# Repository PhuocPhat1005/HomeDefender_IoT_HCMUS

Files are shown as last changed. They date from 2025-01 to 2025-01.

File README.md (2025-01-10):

# **HomeDefender IoT (an alarm system integrated with a camera)**

## **1. Introduction**
* In today's technological era, the Internet of Things (IoT) has been growing rapidly, being applied in various aspects of life and bringing numerous benefits and conveniences to people's lives. The development of devices to protect homes remotely via the Internet is no exception. 

* The HomeDefender product is an anti-theft device designed to protect homes by combining sensors, logical rules, and Internet connectivity. This allows homeowners to easily monitor and safeguard their homes anytime and anywhere. With its compact design, stability, and a simple, user-friendly website interface, the product promises to deliver an excellent and reassuring experience for users.

## **2. System Functionality Description**

* The device utilizes a **PIR** motion sensor to detect if someone approaches the house (the monitored area). Depending on the level of intrusion, the device will activate different modes:
	* **Safe Mode (Mode 1 – Safe System Mode):** The LED light remains blue if no intruders are detected.
	* **Alert Mode (Mode 2 – Alert System Mode):** The device will flash a red LED, and the buzzer will emit a "beep-beep-pause" sound pattern for 10 seconds. After 10 seconds, the system will return to Mode 1. If the intruder remains in the alert zone after this period, a notification will be sent to the user's email. This mode will repeat continuously until no further intrusion is detected.
	* **Emergency Alert Mode (Mode 3 – Emergency Warning System Mode):** In emergency situations, the user can activate the emergency alert mode via the website through the **Device Controls** page by pressing the “FORCE ALERT RIGHT NOW” button. The system will immediately emit a continuous buzzer sound and keep the red LED light on until this mode is deactivated. Simultaneously, the system will send a notification to the user's email.
* In addition, the device is equipped with a camera that can stream video anytime the user desires, allowing them to easily monitor and protect their home. The camera also has the capability to take photos automatically or manually, capturing images of intruders as evidence for reporting criminal activity.
* To ensure the captured photos are well-lit, the device includes a flash that can automatically turn on/off based on signals from a light sensor (the darker the environment, the brighter the flash). Alternatively, the user can manually control the flash through the website as a method of intrusion warning.
* The system stores the photos and records the number of alerts issued each day, along with specific timestamps. This feature helps users track and analyze the security situation in their area more effectively.
* If the system determines that the intruder poses a significant threat, an email will be sent to the user immediately to alert them of the potential danger to their home.
* Additionally, the device is connected to a website for easy use and management by the user. After logging in, the user can perform various functions such as:
	-   Adjusting the operating time.
	-   Turning the device on/off.
	-   Manually capturing photos.
	-   Streaming video.
	-   Viewing the alert history.
	-   Accessing stored photos.
* All of these actions can be done quickly and easily through the user-friendly web interface.

## **3. Members Distribution**
| Student ID | Full Name | Tasks |
|:---:| --- | --- |
|  22127322  | Lê Phước Phát | Embedded Developer |
|  22127388  | Tô Quốc Thanh | UI/UX Developer |
|  22127441  | Thái Huyễn Tùng | Reporter |

## **4. Video Demo**
<!-- BEGIN YOUTUBE-CARDS -->
HomeDefender IoT Demo (https://www.youtube.com/watch?v=ZLpqiuz0C70)
<!-- END YOUTUBE-CARDS -->

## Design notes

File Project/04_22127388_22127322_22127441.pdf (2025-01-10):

Project: HomeDefender | Nhóm 4

ĐẠI HỌC QUỐC GIA THÀNH PHỐ HỒ CHÍ MINH

ĐẠI HỌC KHOA HỌC TỰ NHIÊN HỒ CHÍ MINH

KHOA CÔNG NGHỆ THÔNG TIN

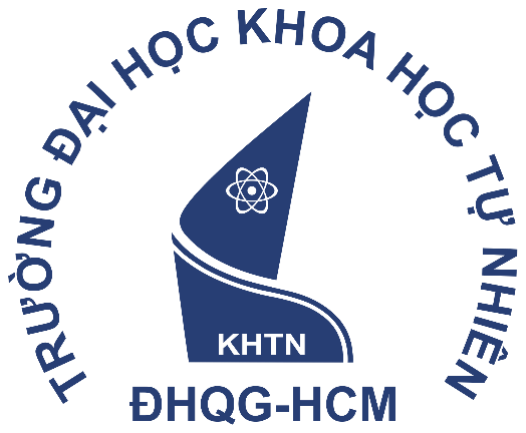
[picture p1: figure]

BÁO CÁO ĐỒ ÁN CUỐI KỲ

VẬT LÝ CHO CÔNG NGHỆ THÔNG TIN

Project: HomeDefender

Giáo viên hướng dẫn:

Thầy: Lê Quốc Hòa

Thầy: Cao Xuân Nam

Thầy: Đặng Hoài Thương

Danh sách thành viên của nhóm 4:

Tô Quốc Thanh – 22127388 (Nhóm trưởng)

Lê Phước Phát – 22127322

Thái Huyễn Tùng – 22127441

## Mục lục

## Phần 1: Giới thiệu

1.1 Giới thiệu
Trong thời đại công nghệ hiện nay, Internet of Things đã và đang phát triển vô cùng mạnh mẽ, được áp dụng vào nhiều lĩnh vực trong đời sống, mang lại nhiều lợi ích và tiện nghi cho cuộc sống của con người. Và việc phát triển thiết bị để bảo vệ ngôi nhà từ xa thông qua Internet cũng không nằm ngoại lệ.

Sản phẩm HomeDefender là thiết bị chống trộm, bảo vệ ngôi nhà bằng cách kết hợp các thiết bị cảm biến, các quy tắc logic cùng với kết nối Internet, từ đó giúp chủ nhà có thể dễ dàng theo dõi và bảo vệ ngôi nhà của mình ở bất kì đâu và bất kì lúc nào. Với thiết kế nhỏ gọn, ổn định cùng giao diện website đơn giản, thân thiện, sản phẩm hứa hẹn sẽ mang lại trải nghiệm tuyệt vời và an tâm cho người sử dụng.
1.2 Mô tả chức năng của toàn hệ thống

Thiết bị sử dụng Cảm biến chuyển động PIR để kiểm tra nếu có người đến gần nhà (khu vực quan sát), tùy theo mức độ xâm nhập mà thiết bị sẽ có những chế độ khác nhau:

+ Chế độ an toàn (mode 1 – safe system mode): Luôn bật đèn Led màu xanh nếu không phát hiện kẻ xâm nhập.

+ Chế độ báo động dựa vào cảm biến hồng ngoại (mode 2 – alert system mode): Thiết bị sẽ nhấp nháy Led đỏ và buzzer sẽ phát tiếng kêu beep beep pause trong vòng 10 giây, sau 10 giây hệ thống sẽ trở lại mode 1, nếu tên trộm vẫn còn trong vùng báo động sau 10 giây thì sẽ gửi thông báo đến mail. Chế độ này sẽ được lặp lại liên tục cho đến khi không còn phát hiện xâm nhập.

+ Chế độ báo động khẩn cấp (mode 3 – emergency warnings system mode): Nếu trong tình huống khẩn cấp, người dùng có thể kích hoạt chế độ báo động khẩn cấp trên Website thông qua trang Device Controls bằng cách bấm nút “FORCE ALERT RIGHT NOW”. Ngay lập tức hệ thống sẽ phát ra tín hiệu buzzer kêu liên hồi và Led đỏ sáng liên tục cho đến khi chế độ này được tắt. Đồng thời, chế độ này cũng sẽ thông báo cho người dùng qua mail.

Bên cạnh đó, thiết bị còn được trang bị Camera để có thể Stream Video bất kì lúc nào mà người dùng muốn để có thể dễ dàng kiểm tra và bảo vệ ngôi nhà của mình. Ngoài ra, Camera này còn có tác dụng chụp ảnh để lưu lại những bức ảnh của kẻ xâm nhập một cách tự động hoặc thủ công, dùng để làm bằng chứng tố cáo tội phạm.

Để đảm bảo các bức ảnh có đầy đủ ánh sáng, thiết bị có trang bị đèn Flash có thể tự động bật/ tắt khi chụp ảnh dựa vào tín hiệu của cảm biến ánh sáng (trời càng tối thì đèn càng sáng), hoặc người dùng có thể bật/ tắt đèn Flash này thủ công thông qua Website như một phương thức cảnh báo xâm nhập.

Hệ thống sẽ lưu lại những bức ảnh và số lần cảnh cáo mỗi ngày với thời gian cụ thể, từ đó giúp người dùng dễ dàng thống kê, theo dõi tình hình an ninh trong khu vực.

Trong trường hợp kẻ xâm nhập được hệ thống đánh giá là nguy hiểm, sẽ có một email được gửi đến người dùng để nhanh chóng cảnh báo cho họ về nguy cơ ngôi nhà bị xâm nhập.

Ngoài ra, thiết bị còn được kết nối với Website để người dùng dễ dàng sử dụng và quản lí, sau khi đăng nhập, người dùng có thể thực hiện các chức năng như : điều chỉnh thời gian hoạt động, bật/ tắt thiết bị, chụp ảnh thủ công, stream video, xem lịch sử cảnh báo, xem ảnh đã lưu,.... một cách dễ dàng và nhanh chóng.

## Phần 2: Chi tiết sản phẩm

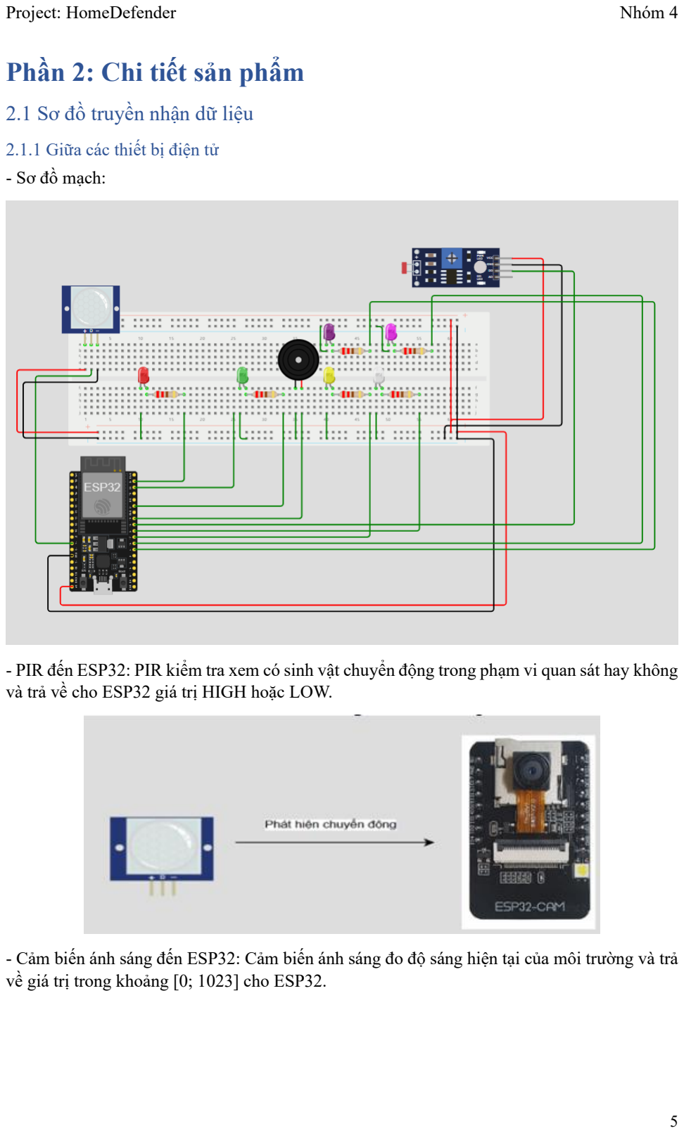
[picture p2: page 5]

2.1 Sơ đồ truyền nhận dữ liệu

2.1.1 Giữa các thiết bị điện tử
- Sơ đồ mạch:
- PIR đến ESP32: PIR kiểm tra xem có sinh vật chuyển động trong phạm vi quan sát hay không và trả về cho ESP32 giá trị HIGH hoặc LOW.
- Cảm biến ánh sáng đến ESP32: Cảm biến ánh sáng đo độ sáng hiện tại của môi trường và trả về giá trị trong khoảng [0; 1023] cho ESP32.

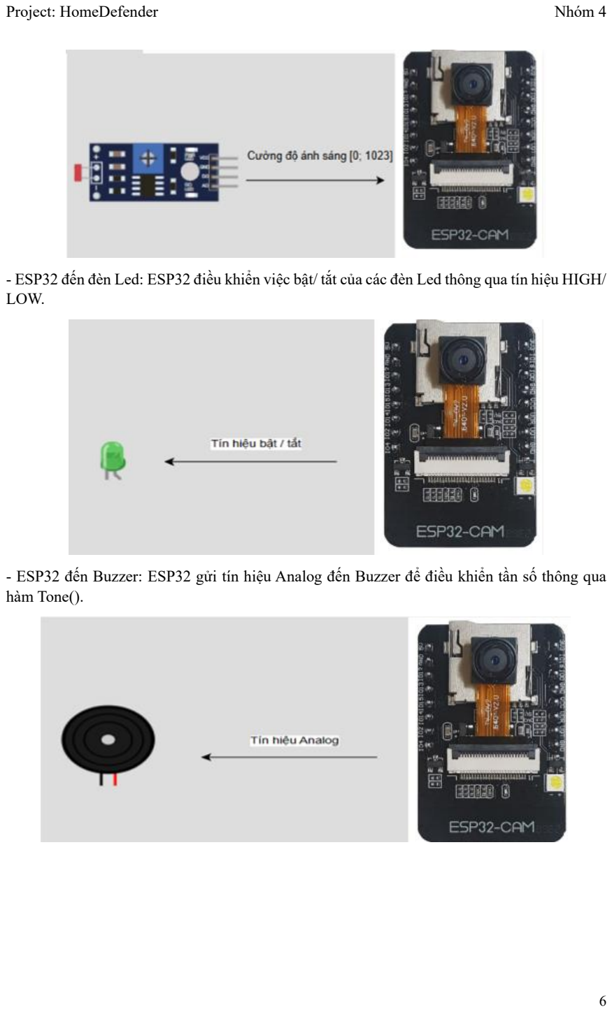
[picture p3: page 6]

- ESP32 đến đèn Led: ESP32 điều khiển việc bật/ tắt của các đèn Led thông qua tín hiệu HIGH/ LOW.
- ESP32 đến Buzzer: ESP32 gửi tín hiệu Analog đến Buzzer để điều khiển tần số thông qua hàm Tone().

2.1.2 Giữa các thiết bị điện tử với website

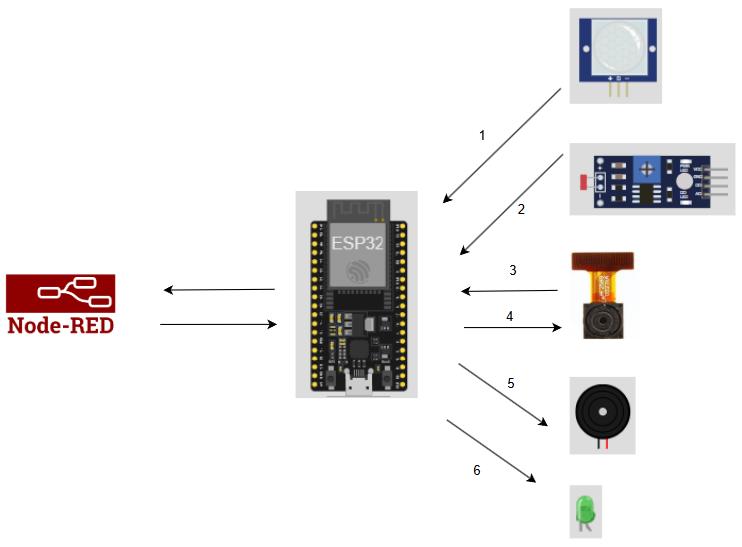
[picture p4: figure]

Website gửi/ nhận thông tin với các thiết bị điện tử thông qua trung tâm điều khiển là ESP32.

- (1): PIR gửi tín hiệu có/ không phát hiện xâm nhập đến cho Website thông qua giá trị HIGH/ LOW.
- (2): Cảm biến ánh sáng gửi giá trị ánh sáng đo được hiện tại đến Website thông quá giá trị trong khoảng [0; 1023], từ đó Website sẽ biết được trạng thái ánh sáng hiện tại là isDay/ isNight.
- (3): Camera Streaming và gửi hình ảnh/ video quay được trực tiếp đến Website thông qua URL (URL này sẽ là http server được cấu hình sẵn theo cấu trúc sau: http://<WIFI LOCAL IP>/mjpeg/1” với WIFI LOCAL IP sẽ là địa chị local của WIFI mà thiết bị đang được cấu hình).
- (4): Dựa vào đường dẫn stream link đã được cấu hình ở luồng (3), chúng ta sẽ thực hiện tách frame từng ảnh và lưu vào database.
- (5): Website điều khiển Buzzer phát ra âm thanh cảnh báo thông qua giá trị analog.
- (6): Website điều khiển đèn Led bật/ tắt thông qua giá trị HIGH/ LOW.

2.1.3 Giữa website với Firesbase
A. Phần Authentication:

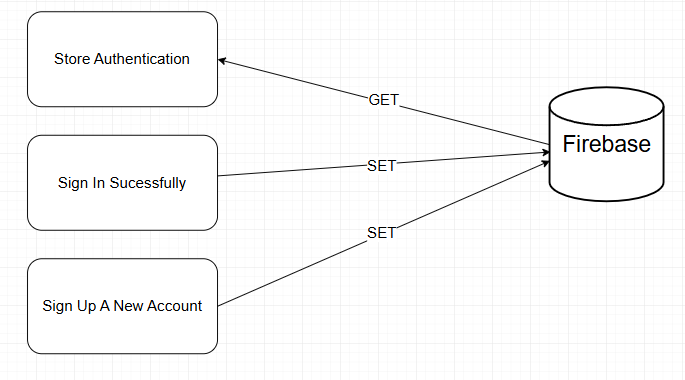
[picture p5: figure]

Luồng 1: Từ Firebase đến Store Authentication

Dữ liệu từ Firebase được gọi và truyền đến function Store Authentication, hàm này sẽ nhận được thông tin người dùng ở trạng thái chưa xác thực và tiến hành lưu nó vào toàn cục.

Luồng 2: Từ Sign In Successfully đến Firebase

Sau khi người dùng đăng nhập thành công thì lúc này thông tin xác thực sẽ trở thành true, sau đó nó được gửi và lưu trữ lên trên Firebase.

Luồng 3: Từ Sign Up A New Account đến Firebase

Lúc này người dùng sẽ điền thông tin đăng ký vào form, sau đó thông tin này được gửi và lưu trữ trên Firebase trong trạng thái chưa xác thực.

* Lưu ý: Trạng thái xác thực ở đây nghĩa là khi người dùng đăng nhập thành công sẽ được chuyển đến các trang chức năng đồng thời trạng thái xác thực sẽ trở thành true. Tuy nhiên, nếu người dùng tiến hành đăng xuất thì trạng thái xác thực sẽ trở thành false.

B. Phần Device Controls:

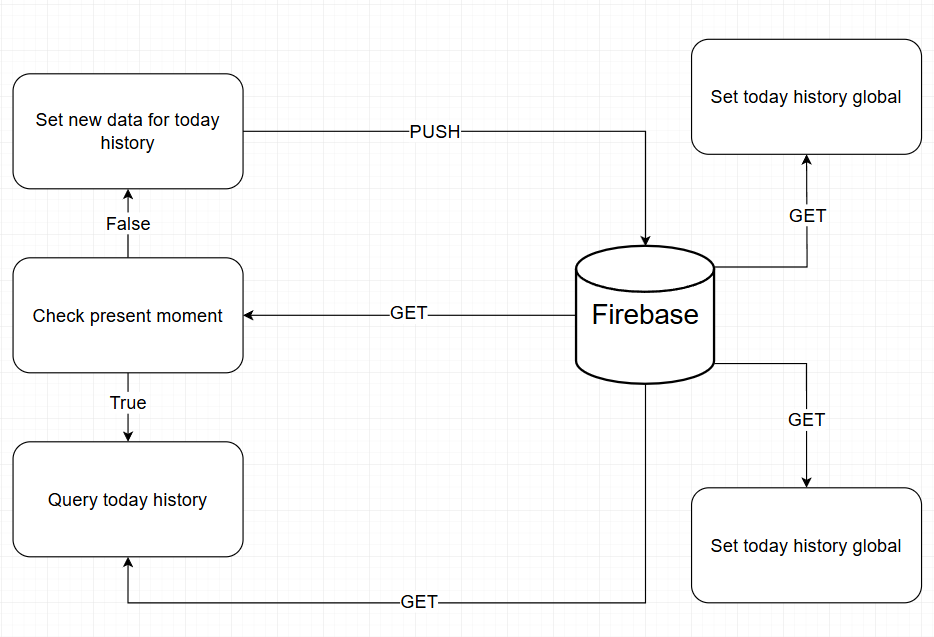
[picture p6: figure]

Luồng 1: Từ Firebase đến Check present moment

Dữ liệu từ Firebase (cụ thể là trường History) sẽ được gửi đến hàm Check present moment để kiểm tra xem dữ liệu về lịch sử cho ngày hôm nay đã tồn tại hay chưa. Đồng thời tạo ra biến toàn cục history_object_key để lưu trữ key object tương ứng với object của lịch sử hôm nay.

Luồng 2: Từ Firebase dến Query today history

Sau khi kiểm tra rằng lịch sử ngày hôm nay đã được tạo thì hàm sẽ tiến hành lấy dữ liệu từ Firebase ứng với biến toàn cục history_object_key. Sau đó dữ liệu đó được đưa vào hàm Set today history global để lưu vào hiến toàn cục today_history.

Luồng 3: Từ Set new data for today history đến Firebase

Nếu lịch sử cho ngày hôm này chưa tồn tại thì sẽ tiến hành lưu lịch sử cho ngày hôm nay vào 1 object và gửi nó đến Firebase để lưu trữ. Sau đó dữ liệu đó được đưa vào hàm Set today history global để lưu vào hiến toàn cục today_history.

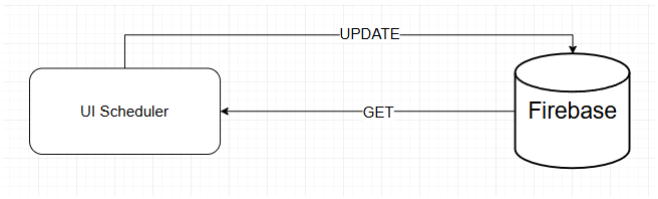
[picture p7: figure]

Luồng 4: Từ Firebase đến UI Shceduler (Giao diện xếp lịch hoạt động cho thiết bị)

Ở phần này, trang web sẽ tiến hành lưu lại trên Firebase lịch hoạt động của thiết bị mà người dùng đã chuẩn bị. Nếu người dùng có cập nhật hay thêm, xóa và sửa lịch thì thông tin đó sẽ được cập nhật lại trong Firebase. Firebase sẽ trả về thông tin lịch sau khi đã chỉnh sửa để hiện ra giao diện trang web.

C. Phần Advanced Settings:

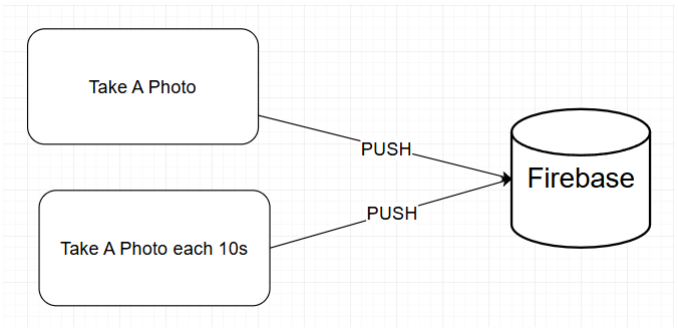
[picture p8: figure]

Luồng 1: Chụp ảnh thủ công đến Firebase

Trong lúc người dùng streaming video, khi nhấn nút chụp ảnh, lúc này ảnh chụp sẽ được gửi đến Firebase để lưu trữ kèm theo 1 số thông tin cụ thể về thời gian ảnh chụp.

Luồng 2: Chụp ảnh tự động mỗi 10s nếu trong vùng nguy hiểm đến Firebase

Khi vật thể bị cảnh bảo và trong khoảng 10 giây kể từ lúc bắt đầu cảnh báo, ảnh sẽ được chụp tự động mỗi 10 giây và được lưu trữ trên Firebase.

D. Phần History:

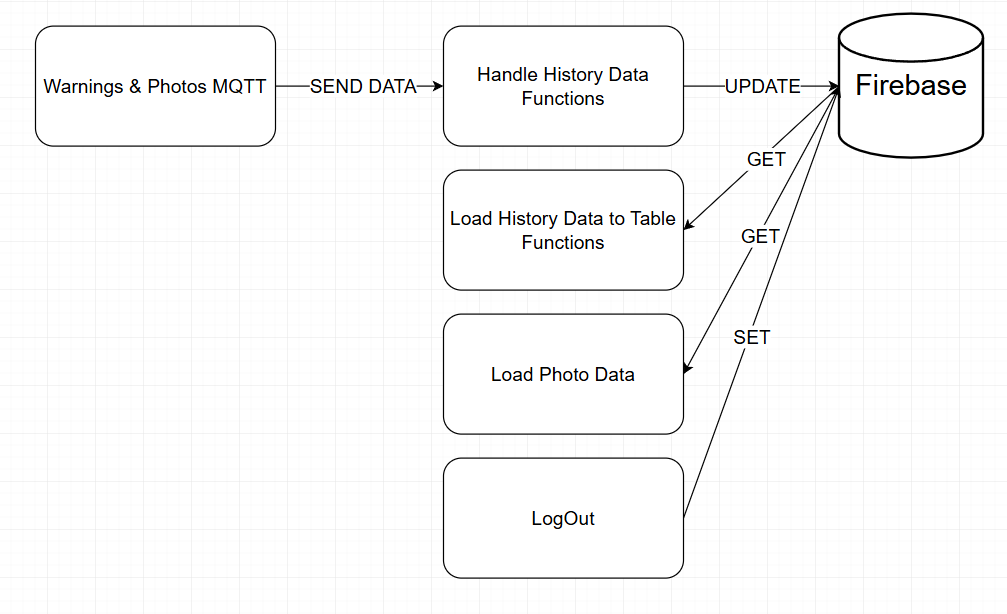
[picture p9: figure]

Luồng 1: MQTT đến Handle History data Functions đến Firebase

Nhận thông tin về số lần warning và số lượng ảnh thông qua MQTT. Sau đó, những dữ liệu này được xử lý thông qua 1 số hàm để trả về dữ liệu lịch sử thích hợp. Cuối cùng, những dữ liệu đã qua xử lý này sẽ được cập nhật và lưu trữ lên trên Firebase.

Luồng 2: Firebase đến Load History Data to Table Functions

Sau khi có được dữ liệu lịch sử, Firebase tiến hành gửi những dữ liệu đó về cho website (Dữ liệu lúc này chỉ là số lượng cảnh báo và số hình ảnh trong ngày). Lúc này, website sẽ sử dụng những dữ liệu đó và tiến hành hiển thị lên trên website.

Luồng 3: Firebase đến Load Photo Data

Lúc này, trang website sẽ nhận dữ liệu hình ảnh từ Firebase và tiến hành hiển thị ra chúng. Người dùng sẽ chọn 1 tấm ảnh tại 1 thời điểm xác định trong menu để tiến hành xem hình ảnh.

Luồng 4: Logout đến Firebase

Khi người dùng bấm đăng xuất, website sẽ gửi về Firebase thông tin người dùng và thay đổi trạng thái xác thực (đang đăng nhập) thành false và người dùng được chuyển về màn hình đăng nhập.

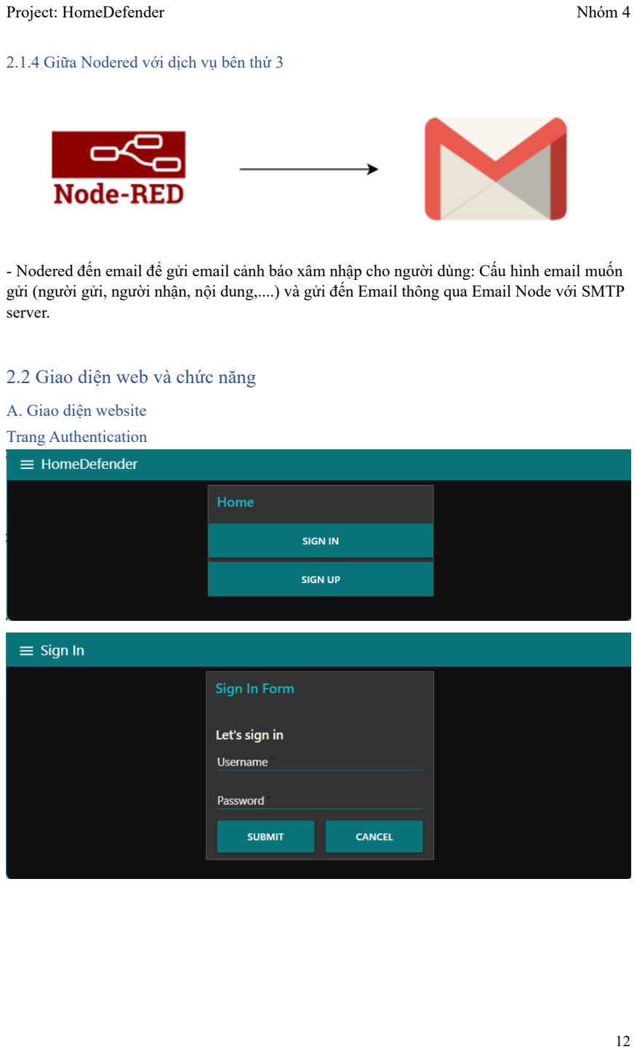
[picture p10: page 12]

2.1.4 Giữa Nodered với dịch vụ bên thứ 3

- Nodered đến email để gửi email cảnh báo xâm nhập cho người dùng: Cấu hình email muốn gửi (người gửi, người nhận, nội dung,....) và gửi đến Email thông qua Email Node với SMTP server.

2.2 Giao diện web và chức năng

A. Giao diện website
Trang Authentication

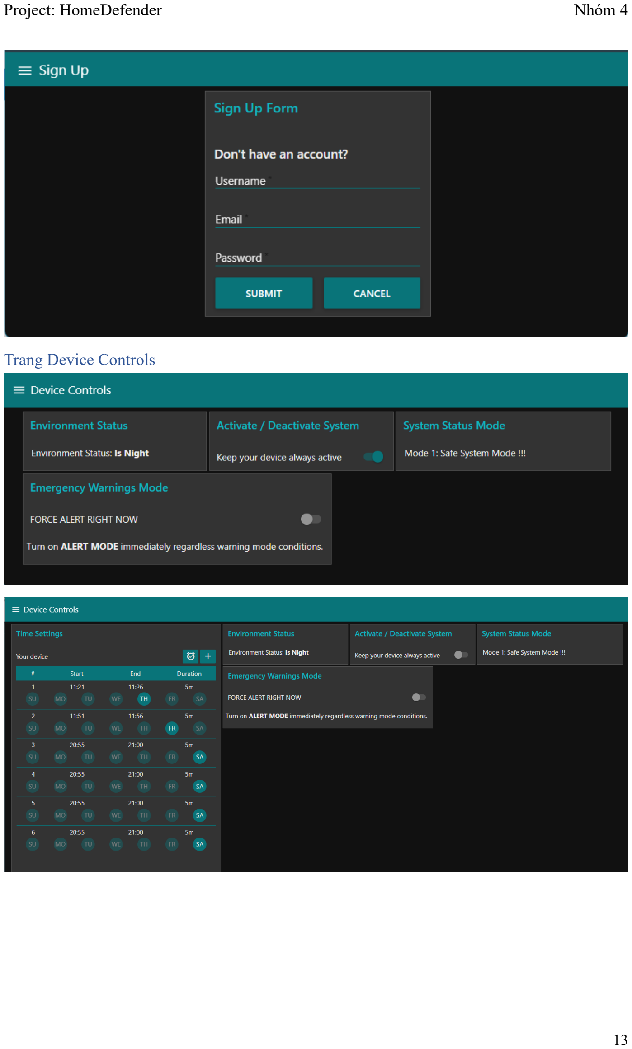
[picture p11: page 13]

Trang Device Controls

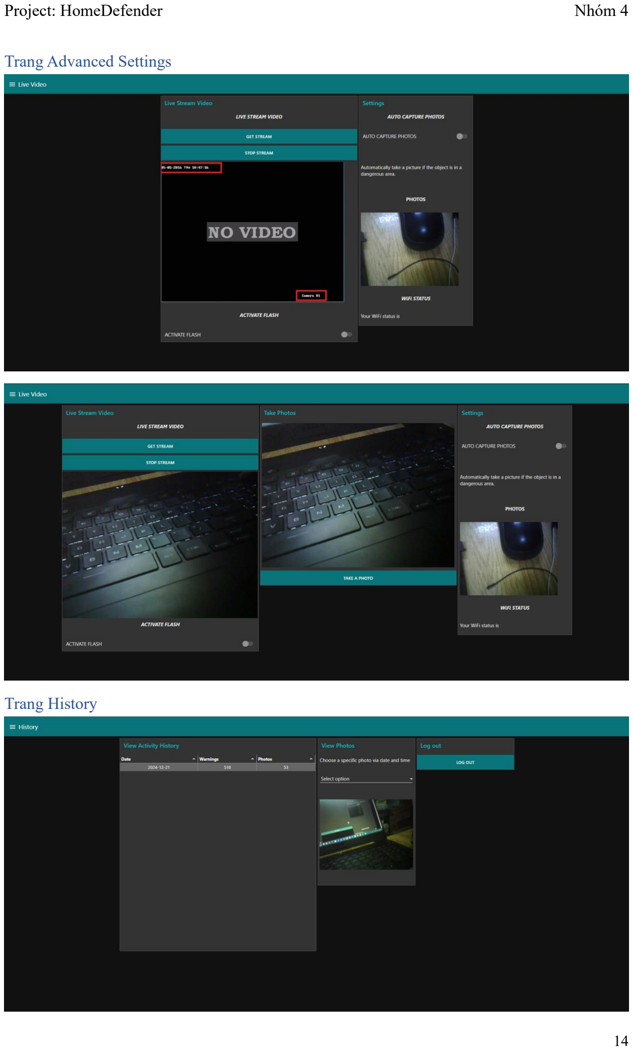
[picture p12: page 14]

Trang Advanced Settings

Trang History

B. Chức năng website
Trang Authentication
Ở trang chủ, trang web sẽ có 2 nút bấm chuyển đến trang đăng nhập và đăng ký.

Ở trang đăng ký, người dùng sẽ:

- Nhập tên tài khoản - Username
- Nhập Email – Email này sẽ dùng để nhận các cảnh báo
- Nhập mật khẩu – Password

Ở trang đăng nhập, người dùng chỉ cần đăng nhập theo Username và Password vừa tạo ở trang đăng ký.

Trang Device Controls
Trong Warning Voice, người dùng mặc định sẽ có âm thanh cảnh báo là beep pause beep.

Trong Photoresistor Sensor, người dùng có thể xem được trạng thái ánh sáng của môi trường xung quanh, quang trở còn có khả năng điều chỉnh độ sáng đèn flash cho phù hợp với môi trường.

Trong Actrive Device, người dùng sẽ được bật mặc định, tức là thiệt bị sẽ luôn hoạt động. Tuy nhiên, người dùng vẫn có thể chỉnh giờ hoạt động của thiết bị theo lịch trình của mình. Để thực hiện chức năng này, người dùng cần phải tắt bỏ đi chức năng hoạt động 24/24 của thiết bị. Sau đó tiến hành chọn và cài đặt lịch trình phù hợp.

Trong System Mode, người dùng sẽ xem được Mode hiện tại của hệ thống. Thông tin sẽ được hệ thống cập nhật bằng một message mỗi khi nó thay đổi Mode.

Trang Advanced Settings
Mặc định, chế độ streaming video sẽ tắt, khi người dùng bấm vào nút Get Stream thì trả về tín hiệu true cho nút Switch, trang web sẽ truy cập vào đường dẫn được trả từ server mqtt “http://<esp32-ip>/mjpeg/1”, trong đó esp32-ip là địa chỉ local ip của wifi mà server đang dùng. Sau đó Web sẽ hiển thị video streaming cho người dùng. Ngược lại khi bấm nút Stop Stream thì trả về tín hiệu false cho nút Switch và lấy hình ảnh “No video” mặc định hiển thị cho người dùng.

Đồng thời, người dùng có thể chụp bất cứ tấm ảnh nào mà mình muốn trong quá trình streaming, bức ảnh được chụp tại thời điểm đó sẽ được hiển thị ngay lập tức trong phần Take Photos.

Bên cạnh đó, người dùng có thể dùng chức năng Chụp hình tự động ở khu vực mà Camera đang quan sát bằng cách bấm vào nút Auto Capture.

Chức năng Alert Mode (Alert Immediately) giúp cho người dùng có thể bật được cảnh báo ở bất kỳ thời điểm nào, kể cả vật thể chưa tiếp cận khu vực cảnh báo. Chức năng này có thể giúp người dùng xua đuổi một số vật thể trước khi chúng cố gắng tiếp cận ngôi nhà. Chức năng này mặc định sẽ được tắt. Hệ thống sẽ hiển thị đèn đỏ sáng liên tục và loa buzzer kêu liên hồi.

Active Flash là chức năng giúp cho người dùng bật được đèn Flash để chiếu sáng. Khi bật đèn Flash sẽ chiếu sáng ở mức tối đa. Chức năng này mặc định cũng sẽ được tắt.

Dòng cuối sẽ là dòng thông báo trạng thái WiFi đã kết nối hay chưa. Nếu kết nối WiFi thành công thì sẽ là TURNED ON còn thất bại sẽ là TURNED OFF.

Trang History
Chức năng View Activity History giúp người dùng xem được lịch sử hoạt động của thiết bị theo ngày. Bảng gồm có 3 cột, mỗi cột người dùng để có thể sắp xếp theo thứ tự tăng hoặc giảm dần:
- Cột Date nghĩa là ngày, cột này sẽ hiển thị thời gian theo chuẩn: YYYY-MM-DD (Năm – Tháng – Ngày).
- Cột Warnings nghĩa là số lần cảnh báo ghi nhận được trong ngày.
- Cột Photos nghĩa là số hình ảnh chụp được trong ngày.

Chức năng View Photos giúp người dùng có thể xem ảnh đã chụp được theo thời điểm chụp tấm ảnh đó. Người dùng chỉ cần chọn khung thời điểm mình muốn xem trong ô selection thì tấm ảnh tương ứng sẽ được hiển thị ra.

Chức năng Logout (Đăng xuất) giúp người dùng đăng xuất ra khỏi trang web.

C. Cấu hình Website

Trang Authentication
Function Verify SignIn

Bước 1: Lấy thông tin từ Form đăng nhập

Bước 2: Lấy thông tin lưu trữ trong biến toàn cục (thông tin này đã được đọc từ Firebase và lưu vào toàn cục)

Bước 3: Nếu 2 thông tin trên là tồn tại thì tiến hành so sánh cái trường dữ liệu, nếu thỏa thì trường is_auth (xác thực) sẽ là true, nếu không thì trường is_auth có giá trị là false.

Function Verify SignUp
Hàm này nhận dữ liệu vào từ Form đăng ký, sau đó tiến hành gán trường xác thực (is_auth) mặc định là false.

Luồng cơ bản:

Lúc đầu sẽ chỉ hiện thị những trang đăng nhập, đăng ký và trang chủ.

Khi người dùng đăng nhập thành công thì sẽ di chuyển người dùng để những trang điều khiển và ẩn trang đăng nhập, đăng ký và trang chủ đi.

Trang Device Controls
Function Preprocessing Scheduler

Hàm này nhận dữ liệu trả về từ Firebase, chuyển đổi thành dạng JSON. Đồng thời trả về trường msg.topic = “update” để Node UI Scheduler có thể cập nhật lịch.

Function Handle Empty Scheduler

Nếu dữ liệu từ Firebase trả về là rỗng hay null thì hàm này sẽ trả về false thông qua MQTT để thông báo rằng lịch rỗng.

Function Day/Night

Hàm này chịu trách nhiệm hiển thị thông tin Sáng/Tối. Kiểm tra msg.payload và chia trường hợp nếu là false nghĩa là sáng còn true nghĩa là tối.

Luồng cơ bản

Dữ liệu nhận tự động từ Firebase, đó là dữ liệu lưu khung thời điểm hoạt động của thiết bị.

Nếu dữ liệu tồn tại, nó sẽ được tiền xử lý và nạp nào Node UI Scheduler (Node Lịch). Node này trả về 2 tham số:

- Tham số thứ nhất là một object JSON lưu thời gian đã được thiết lập.
- Tham số thứ hai nghĩa là nếu thời gian thực tế trùng với thời gian trong lịch sẽ trả về true, ngược lại là false. Các giá trị này sẽ được gửi qua MQTT để kiểm tra thiết bị hoạt động hay không hoạt động.

Nếu dữ liệu không tồn tại, nó sẽ được gửi về MQTT với giá trị false nhằm thông báo lịch rỗng. Và thiết bị sẽ không hoạt động.

Mặc định sẽ ở chế độ hoạt dộng 24/24, nếu người dùng tắt chế độ này, thiết bị sẽ tự động chuyển qua giao diện lịch hoạt động như mô tả bên trên. Và ngược lại.

Người dùng có thể xem được ngoài trời là sáng hay tối thông qua message từ MQTT Photoresistor.

Mặc định thiết bị phát tiếng pause beep pause để cảnh báo. Âm thanh này không thể thay đổi.

Trang Advanced Settings
Function Store current image

Nhận hình ảnh từ MQTT, tiến hành lưu bức ảnh đó kèm với mốc thời gian của bức ảnh đó vào biến global. Thiết lập thêm trường src trong msg.src dùng để hiển thị ảnh/video thông qua Node template.

Function Take a photo

Lấy ra bức ảnh hiện tại từ biến toàn cục global được lưu từ hàm Store current image, sau đó gửi về Firebase để lưu bức ảnh được chụp. Đồng thời gửi giá trị true về MQTT để thông báo làm bật đèn Led ứng với lúc chụp ảnh.

Function Store Capture Photo each 10s

Hàm này nhận hình ảnh thông qua MQTT, tiến hành lưu hình ảnh với mốc thời gian của bức ảnh đó vào Firebase.

Luồng cơ bản

Mặc định streaming video được tắt, khi bật sẽ hiển thị đồng thời cửa sổ chụp ảnh kế bên để người dùng chụp ảnh và xem ảnh mới chụp ngay lập tức.

Chức năng chụp ảnh mỗi 10 giây sẽ tự động chụp ảnh nếu như có vật thể trong vùng cảnh báo quá 10 giây.

Chức năng Alert Mode dùng để bật cảnh báo bất kể vật thể có hay không có trong vùng cảnh báo.

Chức năng Active Flash dùng để bật Flash. Có thể dùng để soi sáng hay chụp ảnh và streaming video.

Chức năng xem trạng thái kết nối WiFi.

Trang History
Function Handle History Data

Đầu tiên tạo ngày giờ hôm nay đảm bảo định dạng: YYYY-MM-DD.

Tiếp theo, lấy ra lịch sử ngày hôm nay thông qua biến global today_history.

Kiểm tra payload của warnings và photos để xác định xem số lượng cảnh báo hay hình ảnh có thêm hay vẫn giữ nguyên.

Tạo ra một object lưu thông tin dữ liệu. Cập nhật lại biến toàn cục today_history là object đó.

Tạo ra dường dẫn động thông qua biến toàn cục history_object_key để đảm báo rằng dữ liệu mới được lưu đúng object chứa dữ liệu của lịch sử cho ngày hôm nay.

Function Preprocessing data image

Do dữ liệu trả về một object chứa các object mà các object được chứa lại chứa những thông tin của 1 ảnh nên logic sẽ có 2 vòng lặp.

Vòng lặp thứ nhất sẽ lặp qua các key trong object lớn ứng với mỗi key ta sẽ lấy ra được 1 object chứa các trường thông tin 1 ảnh.

Vòng lặp thứ 2 sẽ lặp qua những key của object nhỏ, ứng với mỗi key của object nhỏ ta sẽ lấy được các giá trị của nó sau đó lưu vào biến tạm và đẩy nó vào mảng kết quả khi kết thúc vòng lặp thứ 2.

Biến msg.options sẽ là 1 mảng những object với một object sẽ có key là cột mốc thời gian của bức ảnh và value là bức ảnh.

Luồng cơ bản

Trang web sẽ nhận MQTT về số lần cảnh báo và số ảnh chụp được liên tục.

Trang web sẽ nhận dữ liệu lịch sử mới nhất từ Firebase liên tục, đồng nghĩa rằng những thông số lịch sử sẽ được cập nhật liên tục và người dùng có thể thấy được mà không cần tải lại trang.

Trang web cũng sẽ nhận những thông tin hình ảnh mới nhất để đưa vào trang hiển thị cho người dùng. Họ có thể xem ảnh thông qua menu để chọn.

Nút đăng xuất giúp người dùng đăng xuất khỏi trang web.

2.3 Sản phẩm thực tế và thiết kế 3D

- Hình ảnh sản phẩm thực tế:

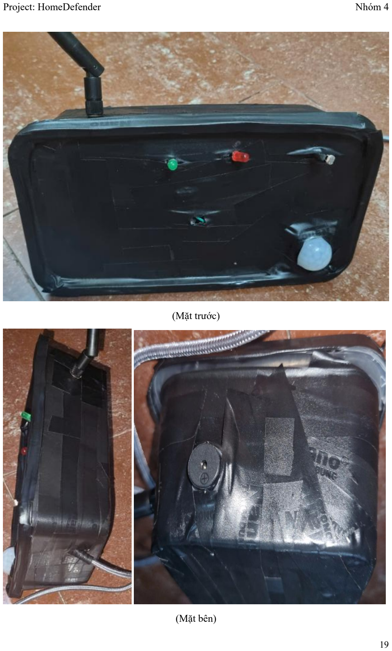
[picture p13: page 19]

(Mặt trước)

(Mặt bên)

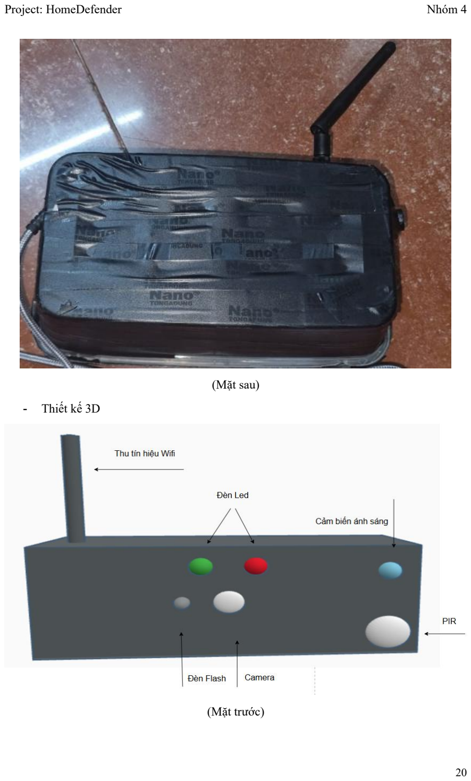
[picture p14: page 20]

(Mặt sau)

- Thiết kế 3D

(Mặt trước)

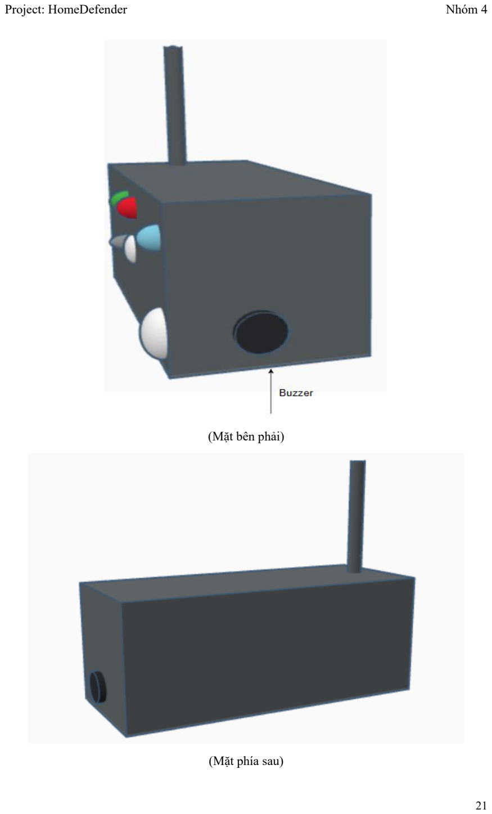
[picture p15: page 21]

(Mặt bên phải)

(Mặt phía sau)

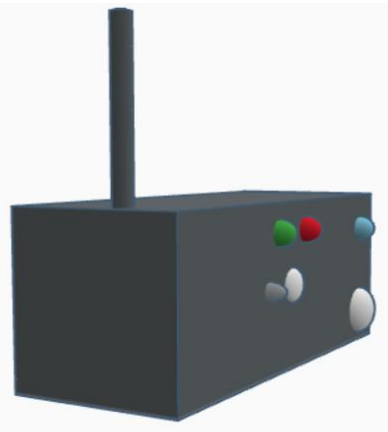
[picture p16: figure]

(Mặt bên trái)

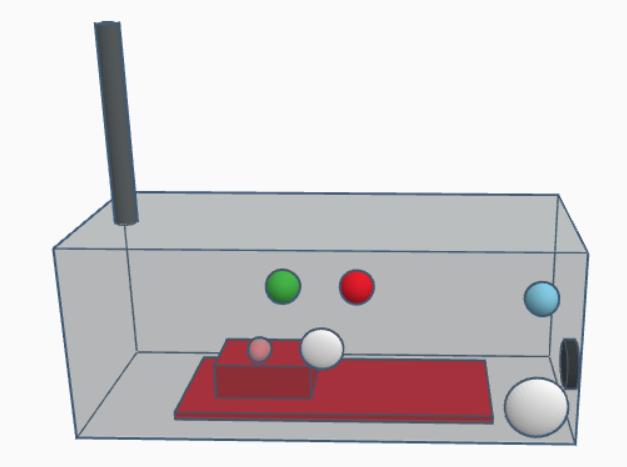
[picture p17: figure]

(Mặt trước và bản mạch)

## Phần 3: Chi tiết linh kiện

3.1. Sản phẩm thực tế
STT | Tên linh kiện | Số lượng
1 | ESP32-CAM[1] | 1
2 | Cảm Biến Chuyển Động Pir HC – Sr501[2] | 1
3 | Cảm biến ánh sáng | 1
4 | LED xanh | 1
5 | LED đỏ | 1
6 | Buzzer | 1
7 | Điện trở 220 ohm | 4
8 | Testboard | 1

[1]: Dùng ESP32-CAM thay vì ESP32 ở proposal, vì ESP32-CAM có tích hợp sẵn Camera, điều này giúp tiết kiệm công sức so với kết nối ESP32 thường với thiết bị Camera.

[2]: Dùng Cảm Biến Chuyển Động Pir HC – Sr501 thay vì Ultrasonic Sensor ở proposal, vì PIR phù hợp với việc chống trộm hơn khi nó chỉ phát hiện các sinh vật, hạn chế nhiễu và tiết kiệm năng lượng hơn.
3.2. Sản phẩm ảo
STT | Tên linh kiện | Số lượng
1 | ESP32 | 1
2 | PIR Motion Sensor | 1
3 | Photoresistor (LDR) Sensor | 1
4 | LED xanh[3] | 1
5 | LED đỏ [4] 1
6 | LED vàng[5] | 1
7 | LED trắng[6] | 1
8 | LED tím[7] | 1
9 | LED hồng[8] | 1
10 | Buzzer | 1
11 | Điện trở 220 ohm | 6
12 | Testboard | 1

[3]: Bóng đèn báo trạng thái an toàn.

[4]: Bóng đèn báo trạng thái không an toàn.

[5]: Bóng đèn báo trạng thái kết nối WiFi.

[6]: Bóng đèn thể hiện đèn Flash.

[7]: Bóng đèn thể hiện việc streaming video.

[8]: Bóng đèn thể hiện việc chụp ảnh.

## Phần 4: Phân công và đánh giá

- Phân công
Giai đoạn | Người thực hiện | Công việc thực hiện
Lập trình và thiết kế mạch IoT | Thái Huyễn Tùng | Chuẩn bị và mua các linh kiện
| Lê Phước Phát | Lập trình và thiết kế mạch thật

Lập trình và thiết kế mạch ảo

Lập trình các thiết bị:
- Input: Camera, cảm biến
chuyển động hồng ngoại
(PIR Motion Sensor, cảm
biến ánh sáng)

- Output: buzzer, flash, đèn led, …

Lắp đặt và hoàn thiện bảng linh kiện điện tử phần cứng.

Tô Quốc Thanh

Lập trình và thiết kế mạch ảo
Chuẩn bị và mua các thiết bị linh kiện.

Thiết kế và lập trình giao diện website

Thái Huyễn Tùng

Thiết kế node-red và lập trình Authentication (đăng nhập, đăng ký) Thiết kế và lập trình chức năng Active và Deactive System
Thiết kế và lập trình Scheduler Thiết kế và lập trình Photoresistor Thiết kế và lập trình View Activity History và View Photos
Thiết kế và lập trình chức năng Đăng Xuất.

Lê Phước Phát

Thiết kế và lập trình chức năng Active Flash
Thiết kế và lập trình chức năng Mode1 (Safe Mode), Mode 2 (Alarm Mode), Mode 3 (Force Mode). Thiết kế và lập trình chức năng Streaming Video
Thiết kế và lập trình chức năng Capture Image with Flash và without Flash.
Thiết kế và lập trình chức năng View Image.
Thiết kế và lập trình chức năng Active Capture Image 10s.

Tô Quốc Thanh

Thiết kế và tạo database (Firebase) để lưu và lấy dữ liệu.
- Thông tin tài khoản người dùng
- Ảnh chụp
- Lịch sử các lần cảnh bảo Thiết kế và lập trình chức năng gửi Email đến người dùng và website. Lập trình HTML cho trang streaming Thiết kế và lập trình chức năng tự chuyển chế độ dựa trên cảm biến. Thiết kế và lập trình System Mode.
Kết nối website và thiết bị linh kiện IoT thông qua MQTT Broker | Thái Huyễn Tùng | Lập trình để nhận các thông tin từ hệ thống và hiển thị lên trang website.
| Lê Phước Phát | Lập trình để gửi các thông tin từ hệ thổng lên web.
Thiết kế 3D | Lê Phước Phát | Thiết kế 3D sản phẩm thật.

| Tô Quốc Thanh | Thiết kế 3D sản phẩm ảo.
Vấn đáp | Lê Phước Phát | Hoàn thiện video demo sản phẩm
| Thái Huyễn Tùng | Hoàn thiện Wokwi (mạch ảo).
| Tô Quốc Thanh | Hoàn thiện slide thuyết trình

Hoàn thiện slide thuyết trình

Hoàn thiện báo cáo nhóm

- Đánh giá thành viên:
Thành viên | Mức độ hoàn thành công việc
Tô Quốc Thanh | 100%
Thái Huyễn Tùng | 100%
Lê Phước Phát | 100%

## Phần 5: Tài liệu tham khảo

- How to Control ESP32 CAM from Node-Red UI using MQTT (https://www.youtube.com/watch?v=L_rqYK_QUCg)
- ESP32-CAM Send base64 image data throgh MQTT (https://www.youtube.com/watch?v=lwdD6XzXMg4)
- HCMUS - IoT - Vật lí đại cương 2 - 1 (https://www.youtube.com/playlist?list=PLzT98eUM-jq9hkS0I9MoQOEGYw_Omix7V)

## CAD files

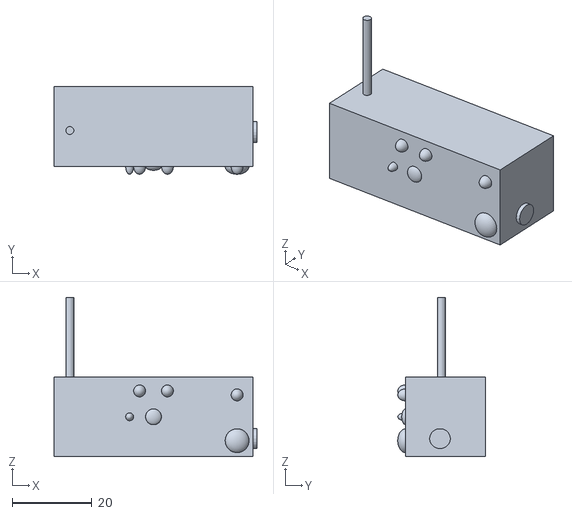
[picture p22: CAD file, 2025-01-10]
Project/04_22127388_22127322_22127441.stl
51.0 x 22.0 x 40.0

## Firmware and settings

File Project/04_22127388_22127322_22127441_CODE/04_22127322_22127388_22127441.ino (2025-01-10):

#include <WiFi.h>
#include <WebServer.h>
#include <FirebaseESP32.h>
#include "PubSubClient.h"

#define APP_CPU 1
#define PRO_CPU 0

#define MAX_ANALOG_READ 4095
#define MAX_BRIGHTNESS 255

#include "src/OV2640.h"

#include <esp_bt.h>
#include <esp_wifi.h>
#include <esp_sleep.h>
#include <driver/rtc_io.h>

#define CAMERA_MODEL_AI_THINKER

#include "camera_pins.h"
#include "esp_camera.h"

// Khai báo các chân kết nối
const unsigned int pirPin = 12; // chân OUT của PIR Motion Sensor
const unsigned int ledRedPin = 14; // chân LED đỏ
const unsigned int ledGreenPin = 2; // chân LED xanh
const unsigned int flashPin = 4; // chân của đèn flash
const unsigned int buzzerPin = 15; // chân buzzer
const unsigned int photoresistorPin = 13; // chân PhotoResistor

const unsigned long led_delay_time = 500; // đặt thời gian delay cho mỗi đèn
const unsigned long buzzer_delay_time = 500; // đặt th  ời gian delay cho loa buzzer
const unsigned int photoresistor_threshold = 1000; // ngưỡng ánh sáng để bật flash

const int MAX_PAYLOAD_SIZE = 60000;

const int numSamples = 10;
unsigned long lastAlarmTime = 0;
const unsigned long alarmDuration = 10000; // thời gian báo động tối đa (10 giây)
bool emailSent = false;
unsigned long mode2StartTime = 0;
const unsigned long emailDelay = 10000;

const char* ssid = "KimDuyen";
const char* password = "25032008";
const char* mqtt_server = "broker.mqtt-dashboard.com";
const int mqtt_port = 1883;
const char* uniqueId = "22127999";

const char* topic_subscribe_active_device = "/HomeDefender/ActivateDevice"; // DONE
const char* topic_subscribe_scheduler = "/HomeDefender/ActivateDeviceScheduler"; // DONE
const char* topic_subscribe_streaming_video = "/HomeDefender/ActiveStreamingVideo"; // DONE
const char* topic_subscribe_control_flash = "/HomeDefender/ControlFlash"; // DONE
const char* topic_subscribe_force_alert = "/HomeDefender/ForceAlertMode"; // DONE
const char* topic_publishing_control_flash = "/HomeDefender/FlashStatus"; // DONE
const char* topic_publishing_photoresistor = "/HomeDefender/Photoresistor"; // DONE
const char* topic_publishing_update_history_warnings = "/HomeDefender/UpdateHistoryWarnings"; // DONE
const char* topic_publishing_update_history_photos = "/HomeDefender/UpdateHistoryPhotos"; // DONE
const char* topic_publishing_wifi_status = "/HomeDefender/WiFiStatus"; // DONE
const char* topic_publishing_mqtt_status = "/HomeDefender/MQTTStatus"; // DONE
const char* topic_publishing_force_alert = "/HomeDefender/ForceAlertNotification"; // DONE
const char* topic_system_warning = "HomeDefender/SystemWarning"; // DONE
const char* topic_publishing_system_mode = "/HomeDefender/SystemMode"; // DONE ***
const char* topic_publishing_streaming_video = "/HomeDefender/activeStreamingStatus";
const char* topic_subscribe_take_a_photo = "/HomeDefender/TakeAPhoto"; // DONE
const char* topic_publishing_activate_system_status = "/HomeDefender/activateSystemStatus"; // DONE
const char* topic_publishing_email_warnings = "/HomeDefender/SendWarning"; // DONE
const char* topic_publishing_email_notification = "/HomeDefender/EmailNotification"; // DONE
const char* topic_publishing_get_string_stream_link = "/HomeDefender/GetLinkStream"; //DONE
const char* topic_publishing_get_string_image_link = "/HomeDefender/GetLinkImage"; // DONE
const char* topic_publishing_take_a_photo = "/HomeDefender/TakeAPhotoNotification"; // DONE
const char* topic_subscribe_get_auto_image = "/HomeDefender/GetAutoImages";

WiFiClient espClient;
PubSubClient client(espClient);

bool take_a_photo = false;

OV2640 cam;
WebServer server(80); // Server HTTP cho video streaming

// ===== rtos task handles =========================
// Streaming is implemented with 3 tasks:
TaskHandle_t tMjpeg;   // handles client connections to the webserver
TaskHandle_t tCam;     // handles getting picture frames from the camera and storing them locally
TaskHandle_t tStream;  // actually streaming frames to all connected clients

// frameSync semaphore is used to prevent streaming buffer as it is replaced with the next frame
SemaphoreHandle_t frameSync = NULL;

// Queue stores currently connected clients to whom we are streaming
QueueHandle_t streamingClients;

// We will try to achieve 25 FPS frame rate
const int FPS = 14;

// We will handle web client requests every 50 ms (20 Hz)
const int WSINTERVAL = 100;

bool streamingActive = false;

int wifiReconnectAttempts = 0;
const int maxWifiReconnectAttempts = 5;

int mqttReconnectAttempts = 0;
const int maxMqttReconnectAttempts = 5;

bool isAlarming = false; // Biến trạng thái báo động
bool systemActive = true; // mặc định hệ thống đang hoạt động
bool schedulerActive = true; // mặc định hệ thống đang hoạt động

bool flashActive = false; // mặc đinh hệ thống ban đầu không sử dụng flash
bool previousFlashState = false;
int isDay = 0;
int isNight = 1;
bool forceAlert = false;
bool previousWiFiStatus = false;
bool previousMQTTStatus = false;
unsigned long lastWiFiPublish = 0;
unsigned long lastMQTTPublish = 0;
const unsigned long publishInterval = 5000;  // 5 giây

enum SystemStatus { OFF, SCHEDULED, ALWAYS_ON };
SystemStatus currentStatus = OFF;

void resetMode() {
  digitalWrite(ledRedPin, LOW);
  digitalWrite(ledGreenPin, LOW);
  // digitalWrite(ledYellowPin, LOW);
  analogWrite(flashPin, 0);
  noTone(buzzerPin);
  digitalWrite(pirPin, LOW);
  isAlarming = false;
  forceAlert = false;
}

// Kết nối WiFi
void WifiConnect() {
  wifiReconnectAttempts = 0;
  WiFi.mode(WIFI_STA);
  WiFi.begin(ssid, password);

  Serial.println("Connecting to WiFi ...");

  unsigned long previousMillis = millis();
  
  while (WiFi.status() != WL_CONNECTED && wifiReconnectAttempts < maxWifiReconnectAttempts) {
    if (millis() - previousMillis >= 1000) { // Chỉ chạy đoạn này sau 500ms
      previousMillis = millis();
      wifiReconnectAttempts++;
      Serial.print("Attempt ");
      Serial.print(wifiReconnectAttempts);
      Serial.println(" to connect to WiFi...");
    }
  }

  if (WiFi.status() == WL_CONNECTED) {
    Serial.println("\nWiFi Connected !!!");
    wifiReconnectAttempts = 0; 
  } else {
    Serial.println("\nFailed to connect to WiFi.");
  }
}

// DONE
void connectMqttServer() {
  mqttReconnectAttempts = 0;
  while (!client.connected() && mqttReconnectAttempts < maxMqttReconnectAttempts) {
    Serial.println("Connecting to MQTT...");
    if (client.connect(uniqueId)) { // Tên client
      Serial.println("Connected to MQTT!");
      Serial.println("Subcribing ...");

      if (client.subscribe(topic_subscribe_active_device)) {
        Serial.println("Subscribed to topic: ");
        Serial.println(topic_subscribe_active_device);
      } else {
        Serial.println("Subscription of Active Device failed!");
      }

      if (client.subscribe(topic_subscribe_scheduler)){
        Serial.println("Subscribed to topic: ");
        Serial.println(topic_subscribe_scheduler);
      }
      else {
        Serial.println("Subscription of Scheduler failed!");
      }

      if (client.subscribe(topic_subscribe_control_flash)){
        Serial.println("Subscribed to topic: ");
        Serial.println(topic_subscribe_control_flash);
      }
      else{
        Serial.println("Subscription of Control Flash failed!");
      }

      if (client.subscribe(topic_subscribe_streaming_video)){
        Serial.println("Subscribed to topic: ");
        Serial.println(topic_subscribe_streaming_video);
      }
      else{
        Serial.println("Subscription of Streaming Video failed!");
      }

      if (client.subscribe(topic_subscribe_take_a_photo)){
        Serial.println("Subscribed to topic: ");
        Serial.println(topic_subscribe_take_a_photo);
      }
      else {
        Serial.println("Subscription of Camera Without Flash failed!");
      }

      if (client.subscribe(topic_subscribe_force_alert)){
        Serial.println("Subscribed to topic: ");
        Serial.println(topic_subscribe_force_alert);
      }
      else{
        Serial.println("Subscription of Force Alert Mode failed!");
      }

      if (client.subscribe(topic_subscribe_get_auto_image)){
        Serial.println("Subscribed to topic: ");
        Serial.println(topic_subscribe_get_auto_image);
      }
      else{
        Serial.println("Subscription of Get Auto Images failed!");
      }

      Serial.println("Subcribe topics ...");
      mqttReconnectAttempts = 0;
      break;
    } else {
      Serial.print("Failed, rc=");
      Serial.print(client.state());
      Serial.println(" Trying again in 5 seconds...");  
      delay(5000);
      mqttReconnectAttempts++;
    }
  }
  if (!client.connected()) {
    Serial.println("Failed to connect to MQTT after multiple attempts.");
    delay(10000);
  }
}

void publishHistoryData(bool warnings = false, bool photos = false) {
  client.publish(topic_publishing_update_history_warnings, warnings ? "true" : "false");
  client.publish(topic_publishing_update_history_photos, photos ? "true" : "false");
}

void mqttCallback(char* topic, byte* payload, unsigned int length) {
  Serial.print("Topic: ");
  Serial.println(topic);

  if (length == 0){
    Serial.println("Empty payload received.");
    return;
  }

  if (length > MAX_PAYLOAD_SIZE){
    Serial.println("Payload is too large !!!");
    return; 
  }

  String stMessage;
  for (int i = 0; i < length; i++){
    stMessage += (char)payload[i];
  }

  Serial.print("Message: ");
  Serial.println(stMessage);

  if (String(topic) == topic_subscribe_active_device) {
    Serial.println("Handling Activate Device ...");
    if (stMessage == "true"){
      systemActive = true; // bật hệ thống
      Serial.println("Hệ thống đã được kích hoạt !!!");
    }
    else if (stMessage == "false"){
      systemActive = false;
      Serial.println("Hệ thống đã tắt !!!");
      resetMode();
    }
    else{
      Serial.println("Invalid payload received !!!");
    }
  }
  else if (String(topic) == topic_subscribe_control_flash) {
    Serial.println("Handling Control Flash ...");
    if(!systemActive){
      Serial.println("Hệ thống đang tắt! Không thể bật đèn Flash!!!");
      publishSystemWarning("Hệ thống đang tắt! Không thể bật đèn Flash!!!");
      return;
    }
    if (stMessage == "true"){
      flashActive = true;
      Serial.println("Đèn flash đã được kích hoạt !!!");
    }
    else if (stMessage == "false"){
      flashActive = false;
      Serial.println("Đèn flash đã tắt !!!");
    }
    else{
      Serial.println("Invalid payload received !!!");
    }
  }
  else if (String(topic) == topic_subscribe_force_alert){
    Serial.println("Handling Force Alert Mode ...");
    if(!systemActive){
      Serial.println("Hệ thống đang tắt! Không thể kích hoạt Force Alert !!!");
      publishSystemWarning("Hệ thống đang tắt! Không thể kích hoạt Force Alert !!!");
      return;
    }

    if (stMessage == "true"){
      forceAlert = true;
      isAlarming = true; // Báo động luôn được kích hoạt
      lastAlarmTime = millis();
      publishForceAlertNotification(true);
      Serial.println("Chế độ Force Alert đã được kích hoạt !!!");
    }
    else if (stMessage == "false"){
      isAlarming = false;
      forceAlert = false;
      resetMode(); // đặt lại hệ thống về trạng thái ban đầu
      publishForceAlertNotification(false);
      Serial.println("Chế độ Force Alert đã tắt !!!");
    }
    else{
      Serial.println("Invalid payload received !!!");
    }
  }
  else if (String(topic) == topic_subscribe_streaming_video){
    Serial.println("Handling Streaming Video");
    if(!systemActive){
      Serial.println("Hệ thống đang tắt! Không thể Streaming Video!!!");
      publishSystemWarning("Hệ thống đang tắt! Không thể Streaming Video!!!");
      return;
    }

    if (stMessage == "true"){
      streamingActive = true;
      Serial.println("Streaming video activated !!!");
    }
    else if (stMessage == "false"){
      streamingActive = false;
      Serial.println("Streaming Video deactivated!!!");
    }
    else{
      Serial.println("Invalid payload received !!!");
    }
  }
  else if (String(topic) == topic_subscribe_take_a_photo){
    if (stMessage == "true"){
      take_a_photo = true;
      Serial.println("Hệ thống bắt đầu chụp ảnh ....");
    }
    else if (stMessage == "false"){
      take_a_photo = "false";
      Serial.println("Hệ thống hết chụp ảnh ...");
    }
    else{
      Serial.println("Invalid payload received !!!");
    }
  }
  else if (String(topic) == topic_subscribe_scheduler){
    Serial.println("Handling Active System via Scheduler ...");
    if (stMessage == "true"){
      schedulerActive = true;
      Serial.println("Hệ thống đã đặt lịch thành công...");
    }
    else if (stMessage == "false"){
      schedulerActive = false;
      Serial.println("Hệ thống chưa đặt lịch cho sẵn ...");
    }
    else{
      Serial.println("Invalid payload received !!!");
    }
  }
  else if (String(topic) == topic_subscribe_get_auto_image){
    Serial.println("Handling Get Auto Images ...");
    if (stMessage == "true"){
      Serial.println("Hệ thống đã tải ảnh vào database ...");
      publishHistoryData(false, true);
    }
    else if (stMessage == "false"){
      Serial.println("Hệ thống không tải ảnh vào database ...");
    }
    else{
      Serial.println("Invalid payload received !!!");
    }
  }
}

// ======== Server Connection Handler Task ==========================
void mjpegCB(void* pvParameters) {
  TickType_t xLastWakeTime;
  const TickType_t xFrequency = pdMS_TO_TICKS(WSINTERVAL);

  // Creating frame synchronization semaphore and initializing it
  frameSync = xSemaphoreCreateBinary();
  xSemaphoreGive( frameSync );

  // Creating a queue to track all connected clients
  streamingClients = xQueueCreate( 10, sizeof(WiFiClient*) );

  //=== setup section  ==================

  //  Creating RTOS task for grabbing frames from the camera
  xTaskCreatePinnedToCore(
    camCB,        // callback
    "cam",        // name
    4096,         // stacj size
    NULL,         // parameters
    2,            // priority
    &tCam,        // RTOS task handle
    APP_CPU);     // core

  //  Creating task to push the stream to all connected clients
  xTaskCreatePinnedToCore(
    streamCB,
    "strmCB",
    4 * 1024,
    NULL, //(void*) handler,
    2,
    &tStream,
    APP_CPU);

  //  Registering webserver handling routines
  server.on("/mjpeg/1", HTTP_GET, handleJPGSstream);
  server.on("/jpg", HTTP_GET, handleJPG);
  server.onNotFound(handleNotFound);

  //  Starting webserver
  server.begin();

  //=== loop() section  ===================
  xLastWakeTime = xTaskGetTickCount();
  for (;;) {
    server.handleClient();

    //  After every server client handling request, we let other tasks run and then pause
    taskYIELD();
    vTaskDelayUntil(&xLastWakeTime, xFrequency);
  }
}

// Commonly used variables:
volatile size_t camSize;    // size of the current frame, byte
volatile char* camBuf;      // pointer to the current frame

// ==== RTOS task to grab frames from the camera =========================
void camCB(void* pvParameters) {

  TickType_t xLastWakeTime;

  //  A running interval associated with currently desired frame rate
  const TickType_t xFrequency = pdMS_TO_TICKS(1000 / FPS);

  // Mutex for the critical section of swithing the active frames around
  portMUX_TYPE xSemaphore = portMUX_INITIALIZER_UNLOCKED;

  //  Pointers to the 2 frames, their respective sizes and index of the current frame
  char* fbs[2] = { NULL, NULL };
  size_t fSize[2] = { 0, 0 };
  int ifb = 0;

  //=== loop() section  ===================
  xLastWakeTime = xTaskGetTickCount();

  for (;;) {

    //  Grab a frame from the camera and query its size
    cam.run();
    size_t s = cam.getSize();

    //  If frame size is more that we have previously allocated - request  125% of the current frame space
    if (s > fSize[ifb]) {
      fSize[ifb] = s * 4 / 3;
      fbs[ifb] = allocateMemory(fbs[ifb], fSize[ifb]);
    }

    //  Copy current frame into local buffer
    char* b = (char*) cam.getfb();
    memcpy(fbs[ifb], b, s);

    //  Let other tasks run and wait until the end of the current frame rate interval (if any time left)
    taskYIELD();
    vTaskDelayUntil(&xLastWakeTime, xFrequency);

    //  Only switch frames around if no frame is currently being streamed to a client
    //  Wait on a semaphore until client operation completes
    xSemaphoreTake( frameSync, portMAX_DELAY );

    //  Do not allow interrupts while switching the current frame
    portENTER_CRITICAL(&xSemaphore);
    camBuf = fbs[ifb];
    camSize = s;
    ifb++;
    ifb &= 1;  // this should produce 1, 0, 1, 0, 1 ... sequence
    portEXIT_CRITICAL(&xSemaphore);

    //  Let anyone waiting for a frame know that the frame is ready
    xSemaphoreGive( frameSync );

    //  Technically only needed once: let the streaming task know that we have at least one frame
    //  and it could start sending frames to the clients, if any
    xTaskNotifyGive( tStream );

    //  Immediately let other (streaming) tasks run
    taskYIELD();

    //  If streaming task has suspended itself (no active clients to stream to)
    //  there is no need to grab frames from the camera. We can save some juice
    //  by suspedning the tasks
    if ( eTaskGetState( tStream ) == eSuspended ) {
      vTaskSuspend(NULL);  // passing NULL means "suspend yourself"
    }
  }
}

// ==== Memory allocator that takes advantage of PSRAM if present =======================
char* allocateMemory(char* aPtr, size_t aSize) {

  //  Since current buffer is too smal, free it
  if (aPtr != NULL) free(aPtr);


  size_t freeHeap = ESP.getFreeHeap();
  char* ptr = NULL;

  // If memory requested is more than 2/3 of the currently free heap, try PSRAM immediately
  if ( aSize > freeHeap * 2 / 3 ) {
    if ( psramFound() && ESP.getFreePsram() > aSize ) {
      ptr = (char*) ps_malloc(aSize);
    }
  }
  else {
    //  Enough free heap - let's try allocating fast RAM as a buffer
    ptr = (char*) malloc(aSize);

    //  If allocation on the heap failed, let's give PSRAM one more chance:
    if ( ptr == NULL && psramFound() && ESP.getFreePsram() > aSize) {
      ptr = (char*) ps_malloc(aSize);
    }
  }

  // Finally, if the memory pointer is NULL, we were not able to allocate any memory, and that is a terminal condition.
  if (ptr == NULL) {
    ESP.restart();
  }
  return ptr;
}


// ==== STREAMING ======================================================
const char HEADER[] = "HTTP/1.1 200 OK\r\n" \
                      "Access-Control-Allow-Origin: *\r\n" \
                      "Content-Type: multipart/x-mixed-replace; boundary=123456789000000000000987654321\r\n";
const char BOUNDARY[] = "\r\n--123456789000000000000987654321\r\n";
const char CTNTTYPE[] = "Content-Type: image/jpeg\r\nContent-Length: ";
const int hdrLen = strlen(HEADER);
const int bdrLen = strlen(BOUNDARY);
const int cntLen = strlen(CTNTTYPE);


// ==== Handle connection request from clients ===============================
void handleJPGSstream(void)
{
  //  Can only acommodate 10 clients. The limit is a default for WiFi connections
  if ( !uxQueueSpacesAvailable(streamingClients) ) return;


  //  Create a new WiFi Client object to keep track of this one
  WiFiClient* client = new WiFiClient();
  *client = server.client();

  //  Immediately send this client a header
  client->write(HEADER, hdrLen);
  client->write(BOUNDARY, bdrLen);

  // Push the client to the streaming queue
  xQueueSend(streamingClients, (void *) &client, 0);

  // Wake up streaming tasks, if they were previously suspended:
  if ( eTaskGetState( tCam ) == eSuspended ) vTaskResume( tCam );
  if ( eTaskGetState( tStream ) == eSuspended ) vTaskResume( tStream );
}
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
void loop() {
  // Kiểm tra kết nối server MQTT
  checkMqttConnection();

  // Kiểm tra kết nối WiFi
  checkWifiConnection();

  // xử lý MQTT
  client.loop();

  vTaskDelay(1000);
  
  // Xử lý logic hệ thống
  if (!systemActive && !schedulerActive) {
    // Hệ thống tắt hoàn toàn
    if (currentStatus != OFF) {
      currentStatus = OFF;
      publishSystemStatus(currentStatus);
      Serial.println("Hệ thống đang tắt hoàn toàn.");
    }
    resetMode();
  }
  else if (!systemActive && schedulerActive) {
    // Hệ thống hoạt động theo lịch
    if (currentStatus != SCHEDULED) {
      currentStatus = SCHEDULED;
      publishSystemStatus(currentStatus);
      Serial.println("Hệ thống hoạt động theo lịch.");
    }
    activateSystem();
  } 
  else if (systemActive) {
    // Hệ thống hoạt động 24/24
    if (currentStatus != ALWAYS_ON) {
      currentStatus = ALWAYS_ON;
      publishSystemStatus(currentStatus);
      Serial.println("Hệ thống hoạt động 24/24.");
    }
    activateSystem(); // Gọi hàm liên tục để xử lý
  }
}
